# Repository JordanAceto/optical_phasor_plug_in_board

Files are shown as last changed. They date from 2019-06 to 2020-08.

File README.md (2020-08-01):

# NOTE: development of all VCF plug-in boards has been moved here https://github.com/JordanAceto/VCF_plug_in_boards

### This repo will no longer be updated. Follow the above link for the most current files.

# Optical Phasor Plug-In Board

Small 6 stage optical phase shifter PCB, designed to plug into a larger motherboard.

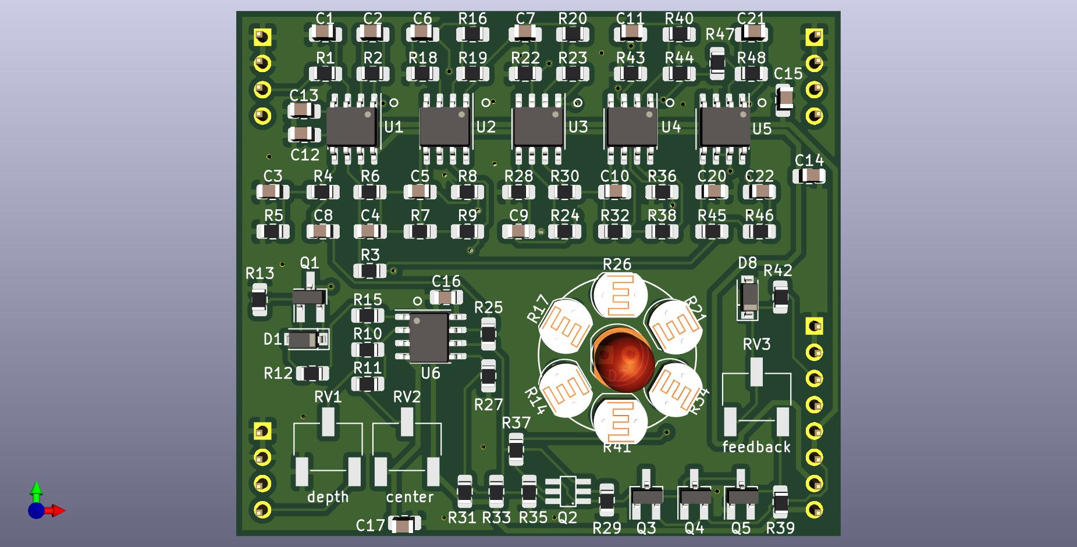
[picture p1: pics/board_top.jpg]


## Details

The main circuit is based on the famous Mutron phasor circuit with the addition of voltage controlled feedback. This PCB includes the audio path and CV inputs for frequency and feedback, but does not include any modulation sources.

The intended use for this board is to plug in to a larger motherboard which contains slots for two of these phasor boards, as well as modulation sources, panel controls, and input/output routing. This motherboard could accept different filter boards sharing this footprint and header layout, for realizing stereo effects of various flavors.

## Inputs

-Audio in: dry audio input to be phase shifted.

-Frequency CV in: 0 volts to +2.048 volts, higher voltage = higher sweep.

-Feedback CV in: 0 volts to +2.048 volts, higher voltage = more feedback.

## Outputs

-Audio out: phase shifted audio output.

## Power Supply Requirements

A bipolar 12 volt power supply capable of supplying 50mA is needed. This will typically come from the motherboard.

## Note About The Light Dependent Resistors

Low on resistance and high off resistance are desirable if a wide sweep range is wanted. Slow/fast response is up to personal taste.

The choice of LED has a large impact on sweep depth. Diffused green LEDs were found to produce good results, but feel free to experiment.

The LED and surrounding LDRs should be protected from ambient light under an opaque cover.

## Calibration

-RV1 (depth trim): trims the depth of incoming frequency CV signals. Turn CW for greater depth and CCW for less depth. Adjust to taste.

-RV2 (center trim): trims the center frequency of the phase shifter. Turn CW for higher center frequency and CCW for lower center frequency. Adjust to taste.

-RV3 (feedback trim): trims the maximum amount of feedback. Turn CW for more maximum feedback and CCW for less maximum feedback. Exercise caution when adjusting this, as extreme settings can result in loud oscillations which could damage your ears or speakers if you are monitoring the sound with a loud amplifier. If you set this trimmer to be right on the edge of oscillation when about +2 volts is applied to the feedback CV input then make sure to sweep the frequency through its entire range, as a setting that doesn't squeal at certain frequency settings may squeal at other settings.

## Parts Ordering
The BOM has a link to a Mouser project with the majority of the parts needed to build the board, with the exception of the LDRs. There is a link to the SmallBear Electronics parts page for their LDRs, which were found to work well. Feel free to experiment with different LDRs.

The BOM also has a link to OSHPark, where you can order boards. If a different PCB house is desired, gerbers and necessary files can be generated from the kicad_docs.

## License
CC by 4.0

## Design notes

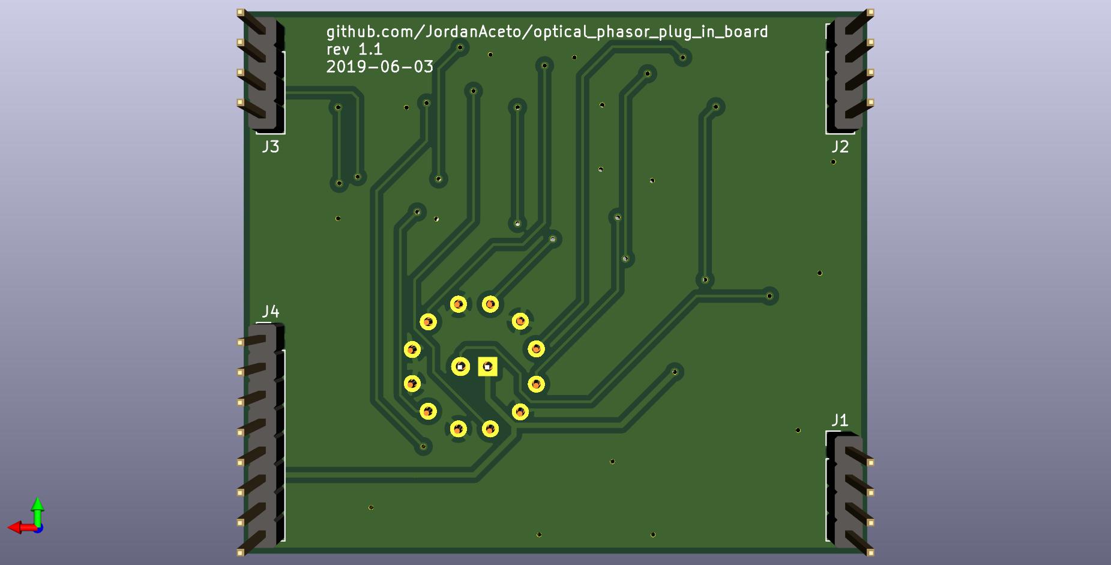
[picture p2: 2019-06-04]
pics/board_bottom.jpg

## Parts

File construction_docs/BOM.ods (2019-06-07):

Reference | Quantity | Value | Footprint | Unit Price | Total Price | Product Page
Mouser Parts
C1 | 1 | 33pF | 0805 | $0.10 | $0.10 | https://www.mouser.com/ProductDetail/KEMET/C0805C330K5GACTU?qs=sGAEpiMZZMs0AnBnWHyRQDFFXrMS8epKKdBCCDfrMeo%3D
C2 C12 C14 C16 C13 C15 C17 | 7 | 100nF | 0805 | $0.10 | $0.70 | https://www.mouser.com/ProductDetail/KEMET/C0805C104M5RACTU
C20 | 1 | 470pF | 0805 | $0.12 | $0.12 | https://www.mouser.com/ProductDetail/Yageo/CC0805KRX7R8BB471
C4 C21 | 2 | 1nF | 0805 | $0.10 | $0.20 | https://www.mouser.com/ProductDetail/Vishay-Vitramon/VJ0805A102KXAAC
C22 | 1 | 220nF | 0805 | $0.68 | $0.68 | https://www.mouser.com/ProductDetail/KEMET/C0805C224M5RACTU
C3 | 1 | 3n3 | 0805 | $0.28 | $0.28 | https://www.mouser.com/ProductDetail/KEMET/C0805C332M5RACTU
C5 C6 C7 C9 C10 C11 | 6 | 6n8 | 0805 | $0.44 | $2.64 | https://www.mouser.com/ProductDetail/Panasonic/ECH-U1C682JX5
C8 | 1 | 470nF | 0805 | $0.21 | $0.21 | https://www.mouser.com/ProductDetail/Yageo/CC0805ZRY5V8BB474
D1 | 1 | 1N914 | SOD-123 | $0.19 | $0.19 | https://www.mouser.com/ProductDetail/Taiwan-Semiconductor/1N914BW-RH
D2 | 1 | green_diffused | 5mm LED, green diffused or to taste | $1.02 | $1.02 | https://www.mouser.com/ProductDetail/Kingbright/WP7083ZGD-G?qs=sGAEpiMZZMtmwHDZQCdlqakguNLvCrcax4VcuwqR0CU%3D
D8 | 1 | 1N5225B | SOD-123 | $0.22 | $0.22 | https://www.mouser.com/ProductDetail/Micro-Commercial-Components-MCC/MMSZ5225B-TP
J1 J2 J3 J4 | 1 | breakaway headers | 2.54mm pin header | $2.78 | $2.78 | https://www.mouser.com/ProductDetail/TE-Connectivity/4-103185-0
Q2 | 1 | BCM847DS135 | SOT457 | $0.41 | $0.41 | https://www.mouser.com/ProductDetail/Nexperia/BCM847DS115
Q3 Q4 | 2 | MMBT3904 | SOT-23 | $0.11 | $0.22 | https://www.mouser.com/ProductDetail/Diodes-Incorporated/MMBT3904-7-F
Q5 Q1 | 2 | MMBT3906 | SOT-23 | $0.11 | $0.22 | https://www.mouser.com/ProductDetail/Diodes-Incorporated/MMBT3906-7-F
R1 | 1 | 3k9 | 0805 | $0.10 | $0.10 | https://www.mouser.com/ProductDetail/Bourns/CR0805-FX-3901ELF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
R10 | 1 | 68k | 0805 | $0.10 | $0.10 | https://www.mouser.com/ProductDetail/Bourns/CR0805-FX-6802ELF
R11 | 1 | 1M | 0805 | $0.10 | $0.10 | https://www.mouser.com/ProductDetail/Bourns/CR0805-FX-1004ELF
R12 | 1 | 10k | 0805 | $0.10 | $0.10 | https://www.mouser.com/ProductDetail/Bourns/CR0805-FX-1002ELF
R13 | 1 | 100R | 0805 | $0.10 | $0.10 | https://www.mouser.com/ProductDetail/Bourns/CR0805-FX-1000ELF
R2 | 1 | 390k | 0805 | $0.10 | $0.10 | https://www.mouser.com/ProductDetail/Bourns/CR0805-FX-3903ELF
R33 R31 | 2 | 47k | 0805 | $0.10 | $0.20 | https://www.mouser.com/ProductDetail/Bourns/CR0805-FX-4702ELF
R35 R29 | 2 | 220R | 0805 | $0.10 | $0.20 | https://www.mouser.com/ProductDetail/Bourns/CR0805-FX-2200ELF
R37 R15 | 2 | 100k | 0805 | $0.10 | $0.20 | https://www.mouser.com/ProductDetail/Bourns/CR0805-FX-1003ELF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
R39 | 1 | 680k | 0805 | $0.10 | $0.10 | https://www.mouser.com/ProductDetail/Bourns/CR0805-FX-6803ELF
R4 | 1 | 8k2 | 0805 | $0.10 | $0.10 | https://www.mouser.com/ProductDetail/Bourns/CR0805-FX-8201ELF
R42 | 1 | 7k5 | 0805 | $0.10 | $0.10 | https://www.mouser.com/ProductDetail/Bourns/CR0805-FX-1202ELF
R45 | 1 | 12k | 0805 | $0.10 | $0.10 | https://www.mouser.com/ProductDetail/Bourns/CR0805-FX-1203ELF
R7 R9 R16 R19 R20 R23 R24 R30 R32 R38 R40 R44 R3 R6 R48 R47 R46 | 17 | 4k7 | 0805 | $0.10 | $1.70 | https://www.mouser.com/ProductDetail/Bourns/CR0805-FX-4701ELF
R8 R18 R22 R28 R36 R43 R5 R25 R27 | 9 | 220k | 0805 | $0.10 | $0.90 | https://www.mouser.com/ProductDetail/Bourns/CR0805-FX-2203ELF
RV1 | 1 | 10k | Bourns_3269W_Vertical | $4.83 | $4.83 | https://www.mouser.com/ProductDetail/Bourns/3269W-1-103LF?qs=sGAEpiMZZMvygUB3GLcD7lKKmqkeksZmGot4dXELruo%3D
RV2 | 1 | 100k | Bourns_3269W_Vertical | $4.83 | $4.83 | https://www.mouser.com/ProductDetail/Bourns/3269W-1-104LF?qs=sGAEpiMZZMvygUB3GLcD7iPUMwpiXMBsQtXtzdbyTwg%3D
RV3 | 1 | 50k | Bourns_3269W_Vertical | $4.83 | $4.83 | https://www.mouser.com/ProductDetail/Bourns/3269W-1-503LF?qs=sGAEpiMZZMvygUB3GLcD7ojGNC38Ba8zkFz9oELLscE%3D
U2 U3 U4 U1 U5 | 5 | RC4558 | SOIC-8_3.9x4.9mm_P1.27mm | $0.41 | $2.05 | https://www.mouser.com/ProductDetail/Texas-Instruments/RC4558DRG4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
U6 | 1 | TL072 | SOIC-8_3.9x4.9mm_P1.27mm | $0.59 | $0.59 | https://www.mouser.com/ProductDetail/Texas-Instruments/TL072CDR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
 |  |  | Mouser Total: |  | $31.32
 |  |  | Link To Mouser Project: |  |  | https://www.mouser.com/ProjectManager/ProjectDetail.aspx?AccessID=9e69f1ee1d
Non-Mouser Parts
R14 R17 R21 R26 R34 R41 | 6 | LDR | LDR_5.0x4.1mm_P3mm | $0.89 | $5.34 | http://smallbear-electronics.mybigcommerce.com/photocells-cds-5mm-diameter/
OSHPark board
Link to OSHPark board: (3 PCB minimum) |  |  |  |  |  | https://oshpark.com/shared_projects/cKb5LmaA

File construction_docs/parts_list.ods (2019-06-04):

Reference | Quantity | Value
C1 | 1 | 33pF
C2 C12 C14 C16 C13 C15 C17 | 7 | 100nF
C20 | 1 | 470pF
C4 C21 | 2 | 1nF
C22 | 1 | 220nF
C3 | 1 | 3n3
C5 C6 C7 C9 C10 C11 | 6 | 6n8
C8 | 1 | 470nF
D1 | 1 | 1N914
D2 | 1 | green_diffused
D8 | 1 | 1N5225B
J1 J2 J3 J4 | 1 | breakaway headers
Q2 | 1 | BCM847DS135
Q3 Q4 | 2 | MMBT3904
Q5 Q1 | 2 | MMBT3906
R1 | 1 | 3k9
R10 | 1 | 68k
R11 | 1 | 1M
R12 | 1 | 10k
R13 | 1 | 100R
R14 R17 R21 R26 R34 R41 | 6 | LDR
R2 | 1 | 390k
R33 R31 | 2 | 47k
R35 R29 | 2 | 220R
R37 R15 | 2 | 100k
R39 | 1 | 680k
R4 | 1 | 8k2
R42 | 1 | 7k5
R45 | 1 | 12k
R7 R9 R16 R19 R20 R23 R24 R30 R32 R38 R40 R44 R3 R6 R48 R47 R46 | 17 | 4k7
R8 R18 R22 R28 R36 R43 R5 R25 R27 | 9 | 220k
RV1 | 1 | 10k
RV2 | 1 | 100k
RV3 | 1 | 50k
U2 U3 U4 U1 U5 | 5 | RC4558
U6 | 1 | TL072

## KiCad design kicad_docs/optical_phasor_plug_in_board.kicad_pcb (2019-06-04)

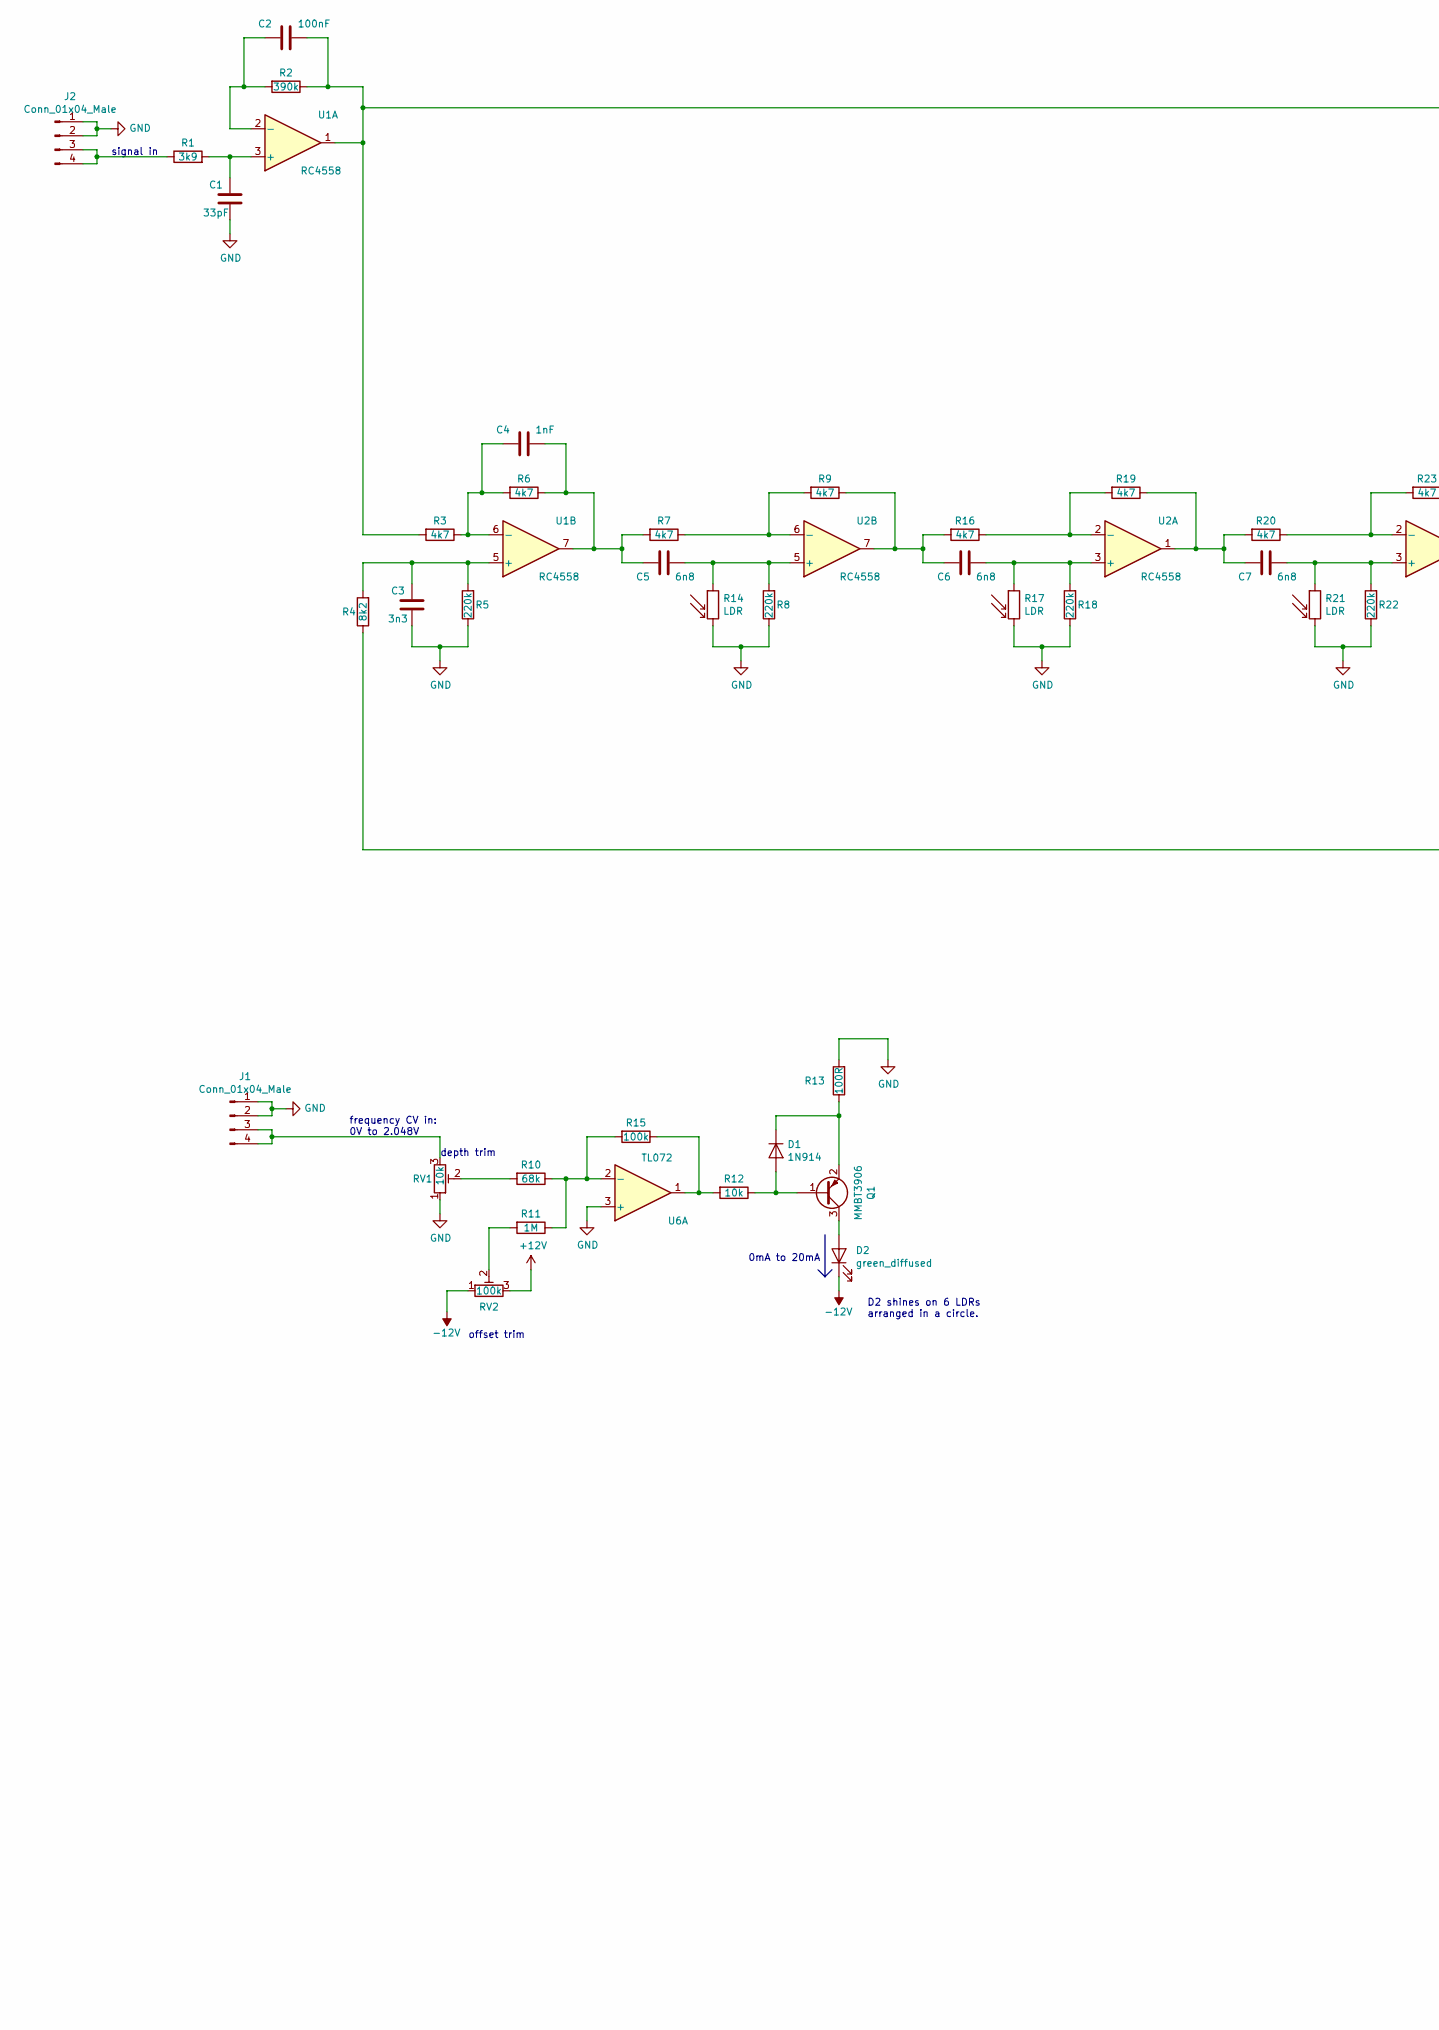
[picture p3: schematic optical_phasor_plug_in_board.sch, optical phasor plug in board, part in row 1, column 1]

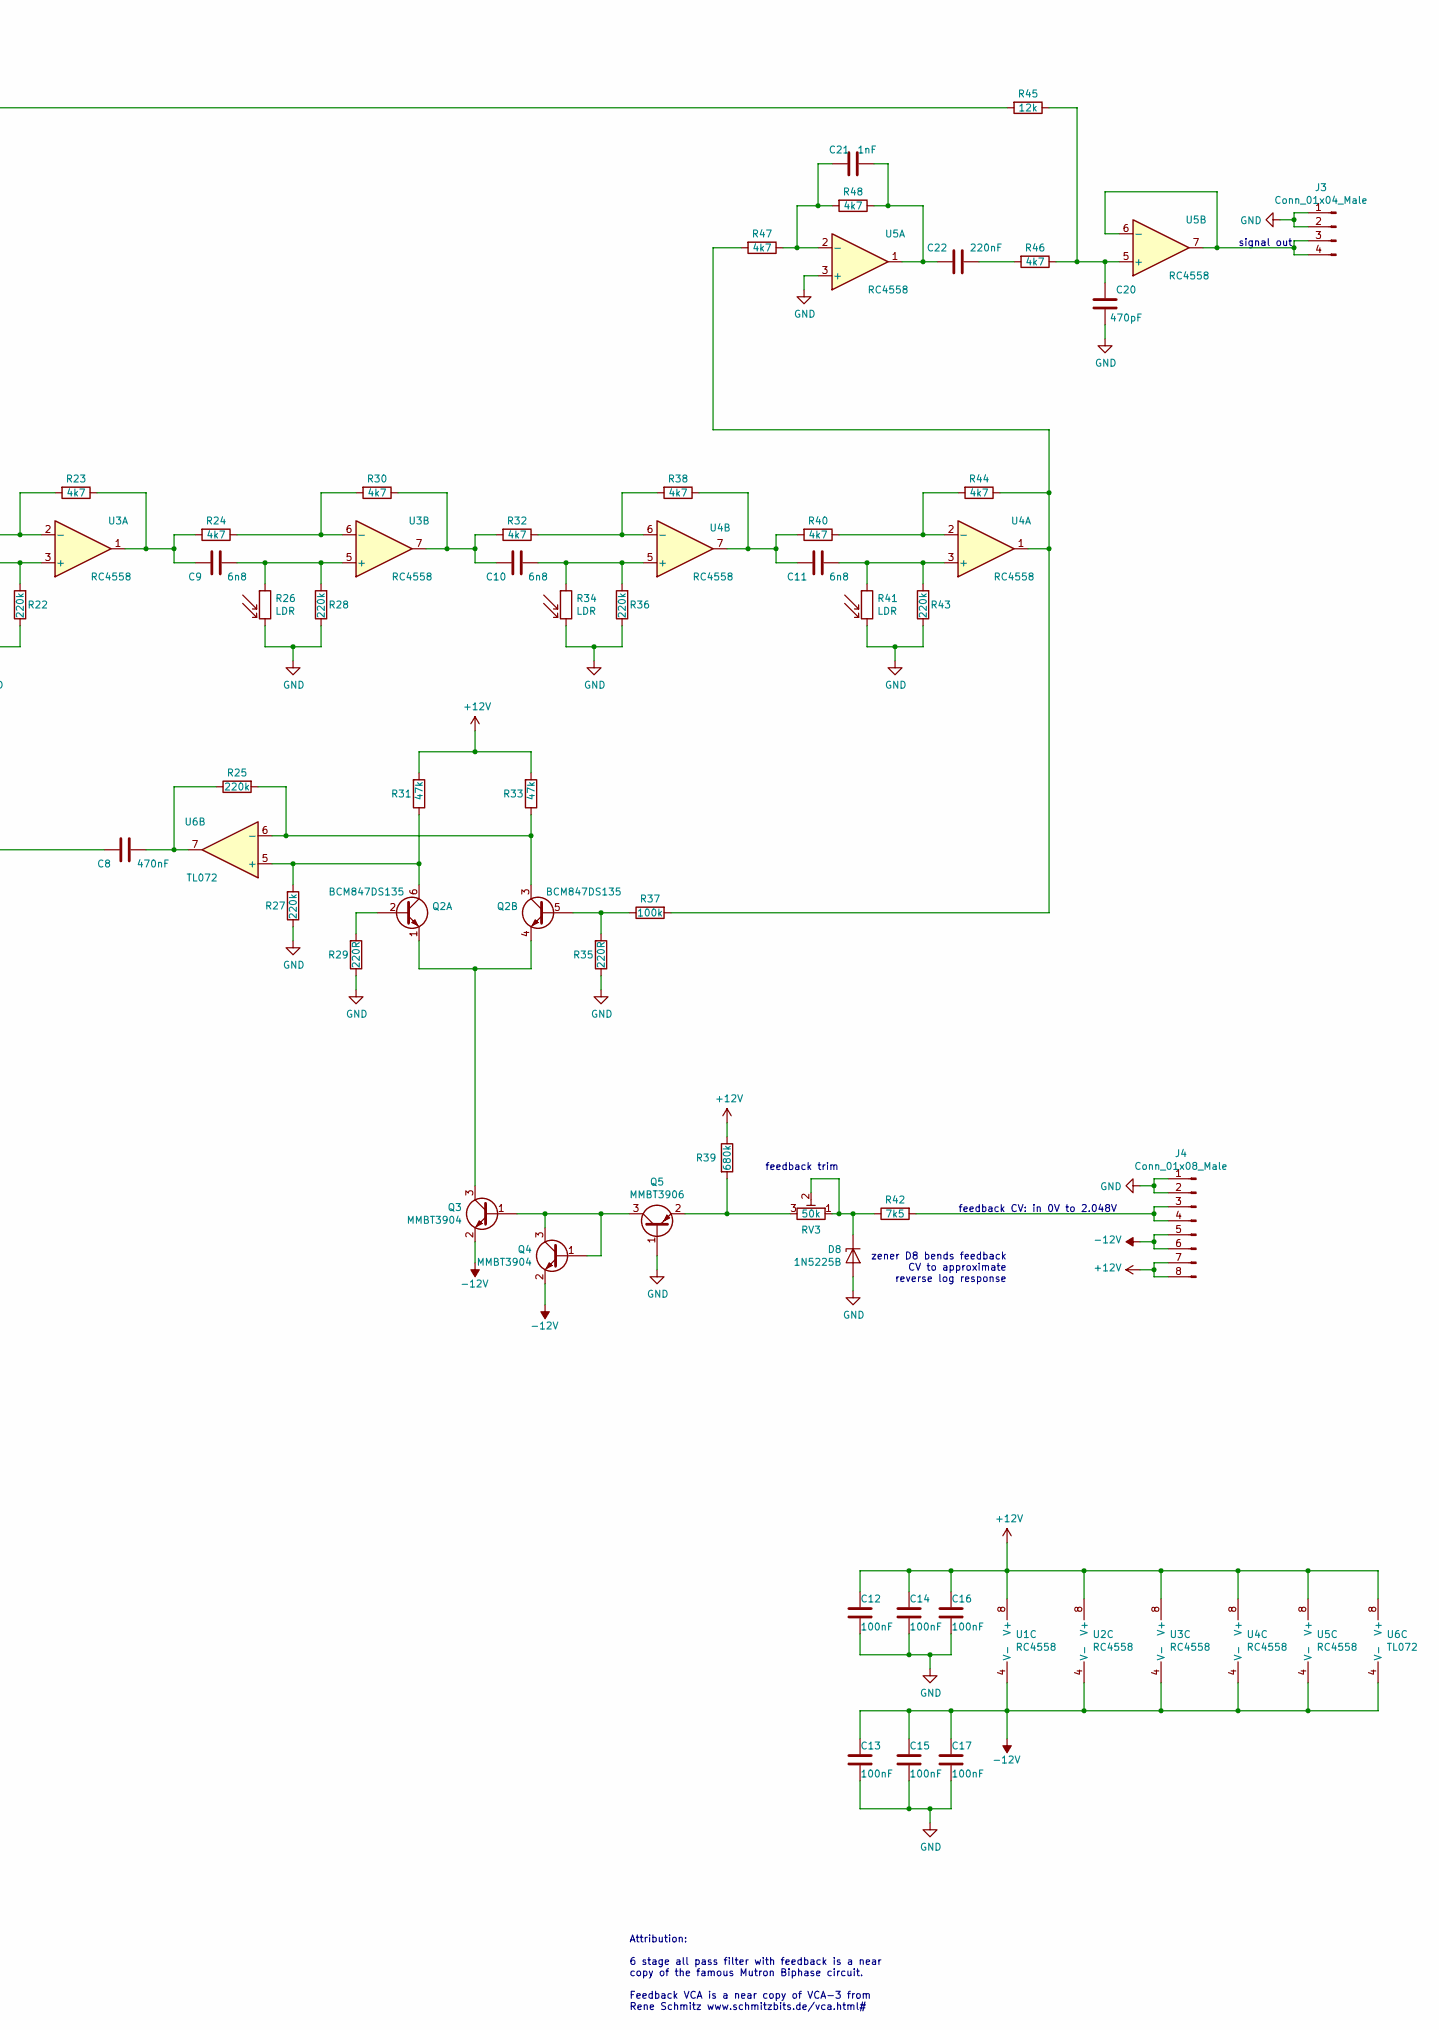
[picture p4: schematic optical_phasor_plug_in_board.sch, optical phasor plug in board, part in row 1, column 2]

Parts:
C1: 33pF; C_0805_2012Metric_Pad1.15x1.40mm_HandSolder
C2, C12, C13, C14, C15, C16, C17: 100nF; C_0805_2012Metric_Pad1.15x1.40mm_HandSolder
C3: 3n3; C_0805_2012Metric_Pad1.15x1.40mm_HandSolder
C4, C21: 1nF; C_0805_2012Metric_Pad1.15x1.40mm_HandSolder
C5, C6, C7, C9, C10, C11: 6n8; C_0805_2012Metric_Pad1.15x1.40mm_HandSolder
C8: 470nF; C_0805_2012Metric_Pad1.15x1.40mm_HandSolder
C20: 470pF; C_0805_2012Metric_Pad1.15x1.40mm_HandSolder
C22: 220nF; C_0805_2012Metric_Pad1.15x1.40mm_HandSolder
D1: 1N914; D_SOD-123
D2: green_diffused; LED_D5.0mm
D8: 1N5225B; D_SOD-123
J1, J2, J3: Conn_01x04_Male; PinHeader_1x04_P2.54mm_Vertical
J4: Conn_01x08_Male; PinHeader_1x08_P2.54mm_Vertical
Q1, Q5: MMBT3906; SOT-23_Handsoldering
Q2: BCM847DS135; SOT457
Q3, Q4: MMBT3904; SOT-23_Handsoldering
R1: 3k9; R_0805_2012Metric_Pad1.15x1.40mm_HandSolder
R2: 390k; R_0805_2012Metric_Pad1.15x1.40mm_HandSolder
R3, R6, R7, R9, R16, R19, R20, R23, R24, R30, R32, R38, R40, R44, R46, R47, R48: 4k7; R_0805_2012Metric_Pad1.15x1.40mm_HandSolder
R4: 8k2; R_0805_2012Metric_Pad1.15x1.40mm_HandSolder
R5, R8, R18, R22, R25, R27, R28, R36, R43: 220k; R_0805_2012Metric_Pad1.15x1.40mm_HandSolder
R10: 68k; R_0805_2012Metric_Pad1.15x1.40mm_HandSolder
R11: 1M; R_0805_2012Metric_Pad1.15x1.40mm_HandSolder
R12: 10k; R_0805_2012Metric_Pad1.15x1.40mm_HandSolder
R13: 100R; R_0805_2012Metric_Pad1.15x1.40mm_HandSolder
R14, R17, R21, R26, R34, R41: LDR; R_LDR_5.0x4.1mm_P3mm_Vertical
R15, R37: 100k; R_0805_2012Metric_Pad1.15x1.40mm_HandSolder
R29, R35: 220R; R_0805_2012Metric_Pad1.15x1.40mm_HandSolder
R31, R33: 47k; R_0805_2012Metric_Pad1.15x1.40mm_HandSolder
R39: 680k; R_0805_2012Metric_Pad1.15x1.40mm_HandSolder
R42: 7k5; R_0805_2012Metric_Pad1.15x1.40mm_HandSolder
R45: 12k; R_0805_2012Metric_Pad1.15x1.40mm_HandSolder
RV1: 10k; Potentiometer_Bourns_3269W_Vertical
RV2: 100k; Potentiometer_Bourns_3269W_Vertical
RV3: 50k; Potentiometer_Bourns_3269W_Vertical
U1, U2, U3, U4, U5: RC4558; SOIC-8_3.9x4.9mm_P1.27mm
U6: TL072; SOIC-8_3.9x4.9mm_P1.27mm

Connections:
+12V: C12.1, C14.1, C16.1, J4.7, J4.8, R31.2, R33.2, R39.1, RV2.3, U1.8 (V+), U2.8 (V+), U3.8 (V+), U4.8 (V+), U5.8 (V+), U6.8 (V+)
-12V: C13.1, C15.1, C17.1, D2.1 (K), J4.5, J4.6, Q3.2 (E), Q4.2 (E), RV2.1, U1.4 (V-), U2.4 (V-), U3.4 (V-), U4.4 (V-), U5.4 (V-), U6.4 (V-)
GND: C1.2, C3.2, C12.2, C13.2, C14.2, C15.2, C16.2, C17.2, C20.1, D8.2 (A), J1.1, J1.2, J2.1, J2.2, J3.1, J3.2, J4.1, J4.2, Q5.1 (B), R5.1, R8.1, R13.2, R14.2, R17.2, R18.1, R21.2, R22.1, R26.2, R27.1, R28.1, R29.1, R34.2, R35.1, R36.1, R41.2, R43.1, RV1.1, U5.3 (+), U6.3 (+)
unnamed: C1.1, R1.2, U1.3 (+)
unnamed: C2.1, R2.1, R3.2, R45.2, U1.1
unnamed: C2.2, R2.2, U1.2 (-)
unnamed: C3.1, R4.2, R5.2, U1.5 (+)
unnamed: C4.1, R3.1, R6.2, U1.6 (-)
unnamed: C4.2, C5.2, R6.1, R7.2, U1.7
unnamed: C5.1, R8.2, R14.1, U2.5 (+)
unnamed: C6.1, R17.1, R18.2, U2.3 (+)
unnamed: C6.2, R9.1, R16.2, U2.7
unnamed: C7.1, R21.1, R22.2, U3.3 (+)
unnamed: C7.2, R19.1, R20.2, U2.1
unnamed: C8.1, R4.1
unnamed: C8.2, R25.1, U6.7
unnamed: C9.1, R26.1, R28.2, U3.5 (+)
unnamed: C9.2, R23.1, R24.2, U3.1
unnamed: C10.1, R34.1, R36.2, U4.5 (+)
unnamed: C10.2, R30.1, R32.2, U3.7
unnamed: C11.1, R41.1, R43.2, U4.3 (+)
unnamed: C11.2, R38.1, R40.2, U4.7
unnamed: C20.2, R45.1, R46.1, U5.5 (+)
unnamed: C21.1, C22.2, R48.1, U5.1
unnamed: C21.2, R47.1, R48.2, U5.2 (-)
unnamed: C22.1, R46.2
unnamed: D1.1 (K), Q1.2 (E), R13.1
unnamed: D1.2 (A), Q1.1 (B), R12.1
unnamed: D2.2 (A), Q1.3 (C)
unnamed: D8.1 (K), R42.1, RV3.1, RV3.2
unnamed: J1.3, J1.4, RV1.3
unnamed: J2.3, J2.4, R1.1
unnamed: J3.3, J3.4, U5.6 (-), U5.7
unnamed: J4.3, J4.4, R42.2
unnamed: Q2.1 (E), Q2.4 (E), Q3.3 (C)
unnamed: Q2.2 (B), R29.2
unnamed: Q2.3 (C), R25.2, R33.1, U6.6 (-)
unnamed: Q2.5 (B), R35.2, R37.1
unnamed: Q2.6 (C), R27.2, R31.1, U6.5 (+)
unnamed: Q3.1 (B), Q4.1 (B), Q4.3 (C), Q5.3 (C)
unnamed: Q5.2 (E), R39.2, RV3.3
unnamed: R7.1, R9.2, U2.6 (-)
unnamed: R10.1, R11.1, R15.2, U6.2 (-)
unnamed: R10.2, RV1.2
unnamed: R11.2, RV2.2
unnamed: R12.2, R15.1, U6.1
unnamed: R16.1, R19.2, U2.2 (-)
unnamed: R20.1, R23.2, U3.2 (-)
unnamed: R24.1, R30.2, U3.6 (-)
unnamed: R32.1, R38.2, U4.6 (-)
unnamed: R37.2, R44.1, R47.2, U4.1
unnamed: R40.1, R44.2, U4.2 (-)

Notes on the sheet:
offset trim
depth trim
zener D8 bends feedback CV to approximate reverse log response
signal in
frequency CV in: 0V to 2.048V
signal out
feedback CV: in 0V to 2.048V
D2 shines on 6 LDRs arranged in a circle.
0mA to 20mA
Attribution: 6 stage all pass filter with feedback is a near copy of the famous Mutron Biphase circuit. Feedback VCA is a near copy of VCA-3 from Rene Schmitz www.schmitzbits.de/vca.html#
feedback trim

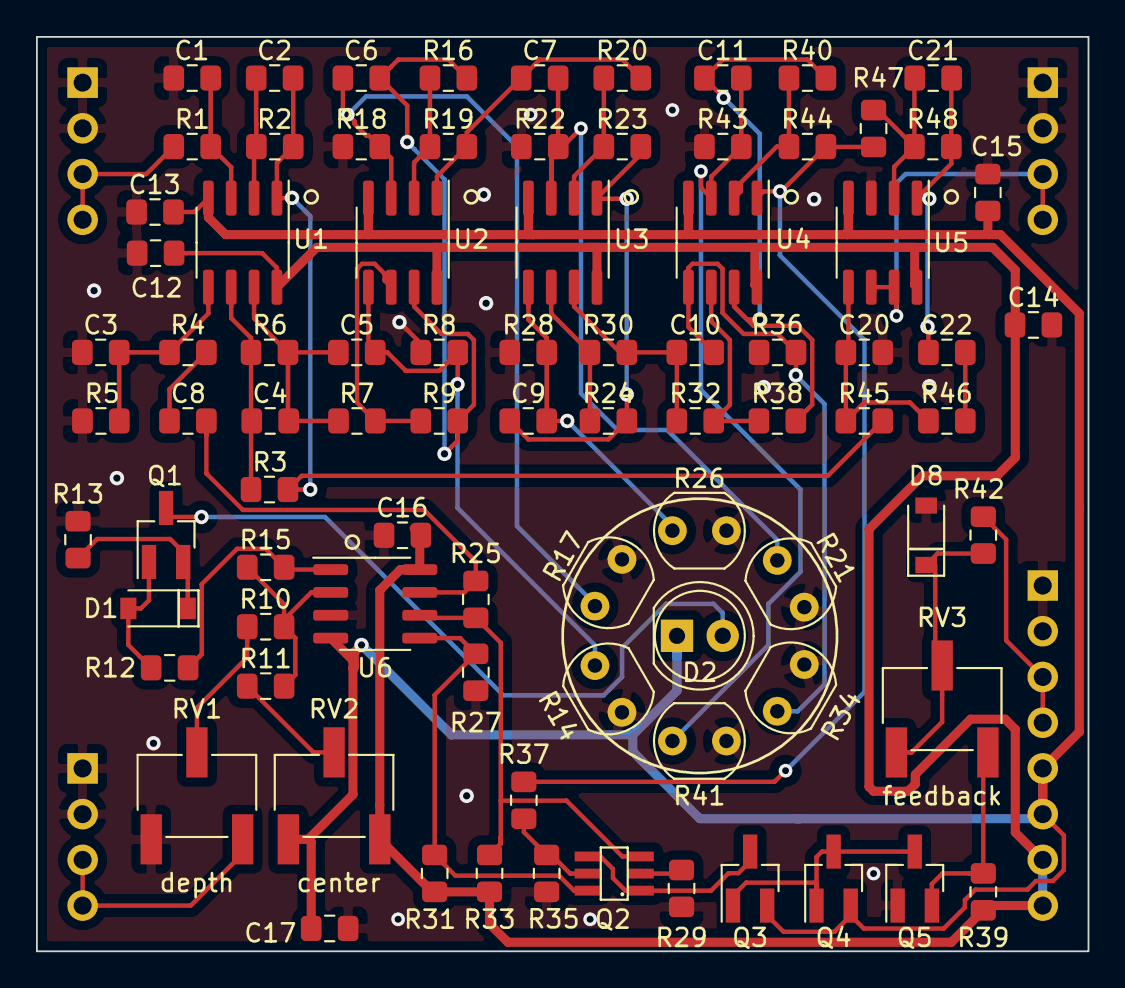
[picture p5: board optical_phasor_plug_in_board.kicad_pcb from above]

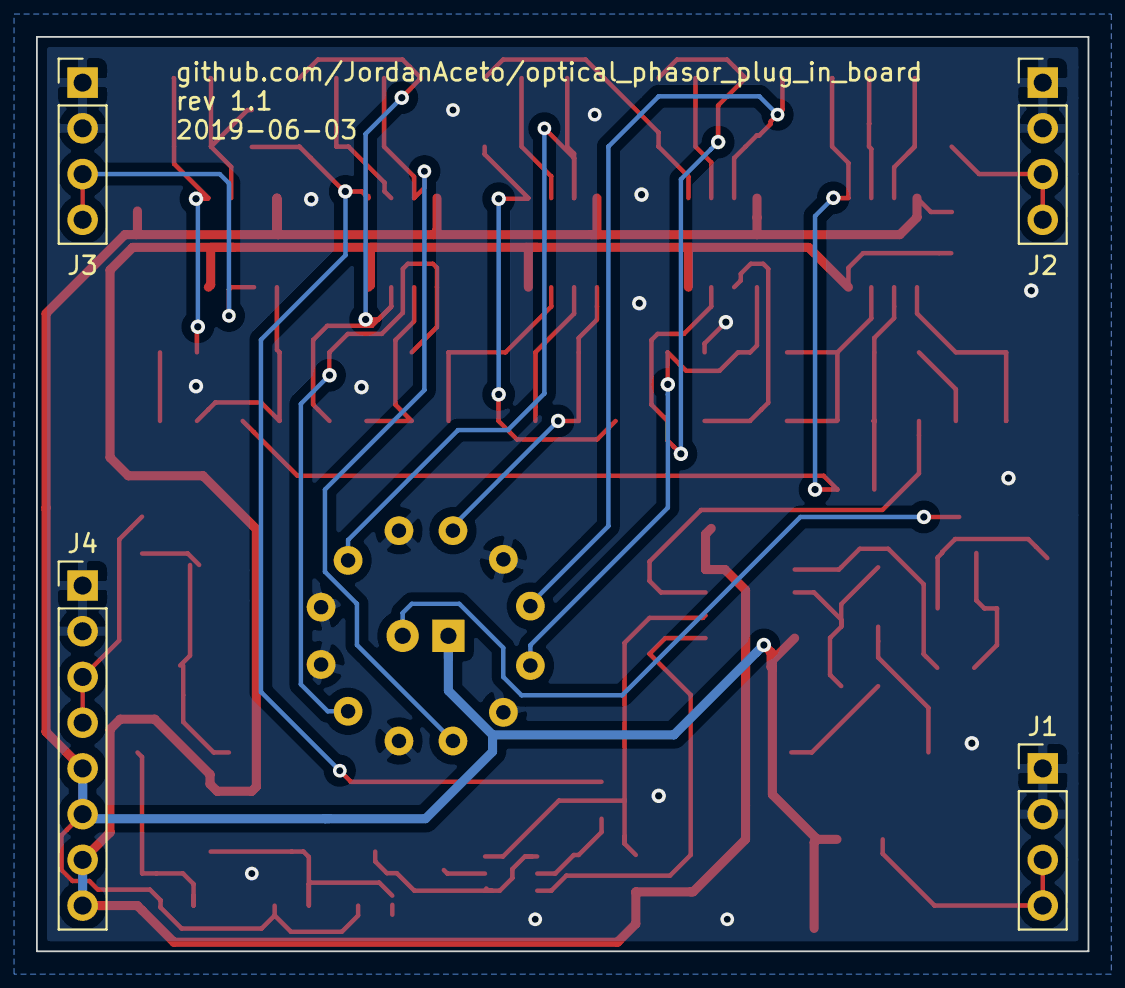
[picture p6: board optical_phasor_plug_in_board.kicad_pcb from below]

Board: 2 copper layers, 58.4 x 50.8 mm, 89 parts (4 on the bottom side), 52 nets.

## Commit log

2019-05-22 add pdf of schematic
2019-05-22 add jpegs of rendered board front and back
2019-05-22 add link to mouser project in BOM
    [optical_phasor_plug_in_board_BOM.ods]
2019-05-24 rename BOM, change APF cap type in BOM
    [optical_phasor_plug_in_board.ods, optical_phasor_plug_in_board_BOM.ods]
2019-05-24 fix mistake with BOM name
    [optical_phasor_plug_in_board.ods, optical_phasor_plug_in_board_BOM.ods]
2019-06-04 rev 1.1
    [BOM.ods, optical_phasor_plug_in_board.kicad_pcb, optical_phasor_plug_in_board.sch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]
2019-06-06 add link to OSHPark board in BOM, tidy up BOM
    [BOM.ods]
2019-06-07 tidy up BOM
    [BOM.ods]

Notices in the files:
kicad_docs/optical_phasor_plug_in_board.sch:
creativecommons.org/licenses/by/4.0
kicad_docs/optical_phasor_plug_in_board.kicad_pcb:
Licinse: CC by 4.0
